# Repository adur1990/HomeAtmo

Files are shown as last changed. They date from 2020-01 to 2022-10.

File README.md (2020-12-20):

# HomeAtmo
Simple ESP32 based BME680 indoor air quality sensor.

## Overview
This is a very basic project, which reads the sensor values from a BME680 sensor (temperature, humidity VOC, CO2 air quality) and computes the [Indoor Air Quality (IAQ)](https://en.wikipedia.org/wiki/Indoor_air_quality) and implemented as an HomeKit Accessory.

## DIY
**Disclaimer: this project uses the proprietary [Bosch Sensortec Environmental Cluster (BSEC) Arduino Library](https://github.com/BoschSensortec/BSEC-Arduino-library) with their own [license](https://github.com/BoschSensortec/BSEC-Arduino-library/blob/master/LICENSE). If you do not agree with this license, you can not use this software. Everything not from the BSEC library uses the GPL 3.0 license**
### Software
#### HomeKit
All relevant HomeKit information has to be given in the `creds.h` file.
Use `include/creds.h.example` as a reference.

#### Wi-Fi
To be able to connect to your Wi-Fi network, provide your SSID and PSK in the `creds.h` file (see above).

#### Flashing
This project uses [PlatformIO](https://platformio.org), which makes it pretty easy to deploy the code.
Simply connect the ESP32 to you computer, import this repo into PlatformIO and use PlatformIO's upload command.
Thats it for the software part.
Head on to the hardware section.

### Hardware
For this project, I use an [ESP32 WROOM NodeMCU Development Board](https://www.amazon.de/dp/B071P98VTG) (~10€) and the [Bosch BME680 Sensor Breakout from BlueDot](https://www.amazon.de/gp/product/B075Y21H24) (~25€).
There are for sure cheaper solutions from AliExpress or similar, but I was not patient enough, so I went with Amazon. If you use different hardware, you have to adjust the case dimensions.

For the power supply, I use a rather standard USB 5V DC adapter to power the ESP32 via the 5V and GND pins.

#### Wiring
The wiring is quite easy.
Connect the VIN pin to the 3V pin of the ESP32, GND to GND.
For I2C, connect the SCK pin to the ESP's SCL (GPIO22) and SDI to SDA (GPIO21).
The ground cable of your USB power supply goes to the 5V pin on the ESP32 and GND to a free GND.

The following fritzing sketch will show you an example, but your actual pinout can be different, so be careful here!

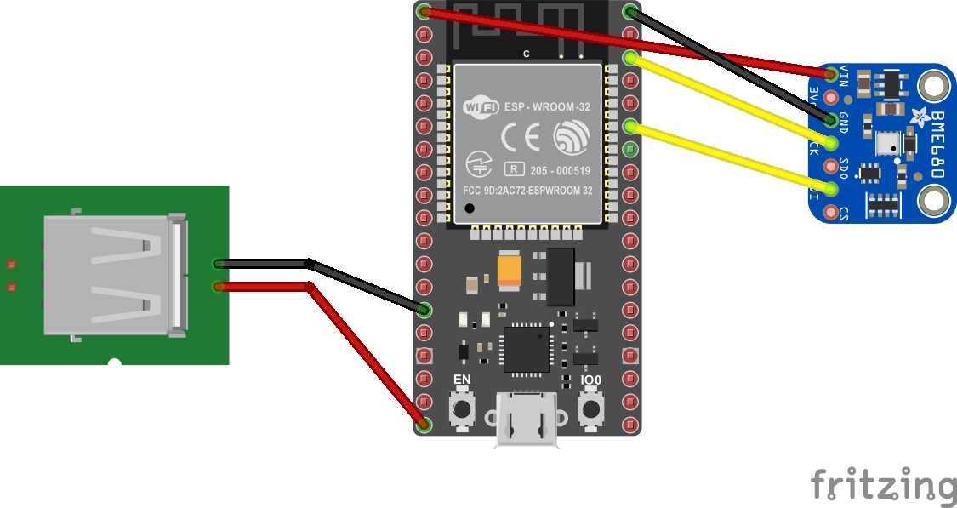
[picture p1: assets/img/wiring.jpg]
LWiring


#### Packaging
*Note: The case does not have a micro USB connector. Flash the ESP32 BEFORE assembling the sensor!*

Use the provided [STL](assets/HomeAtmo.stl) to print the case. Adjust the dimensions according to your hardware.
Pack everything into the case as seen on the following image:

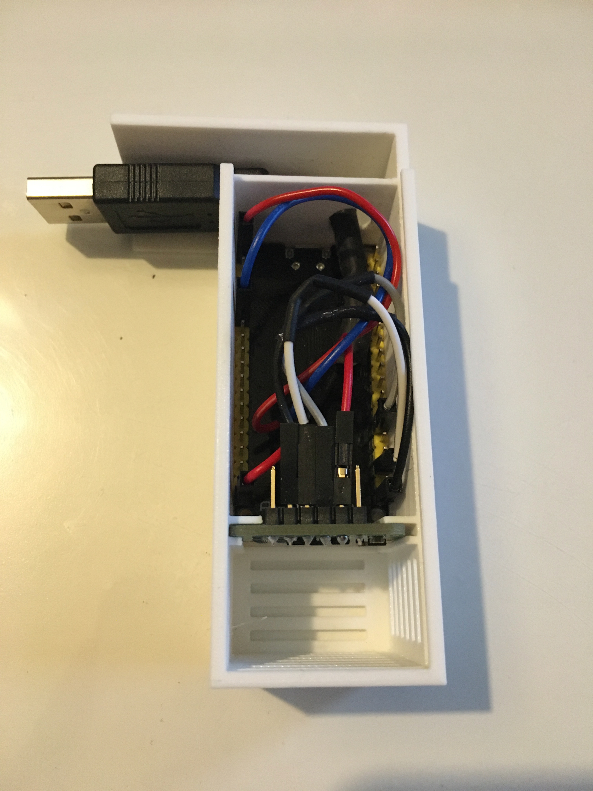
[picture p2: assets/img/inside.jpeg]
Look Inside


You have to fiddle the wires for power supply through the small hole and connect the jumper wires to the corresponding 5V and GND pins.
The sensor itself is put vertically into the corresponding compartment.
Finally, the lid must be closed by pushing it into the slots provided.

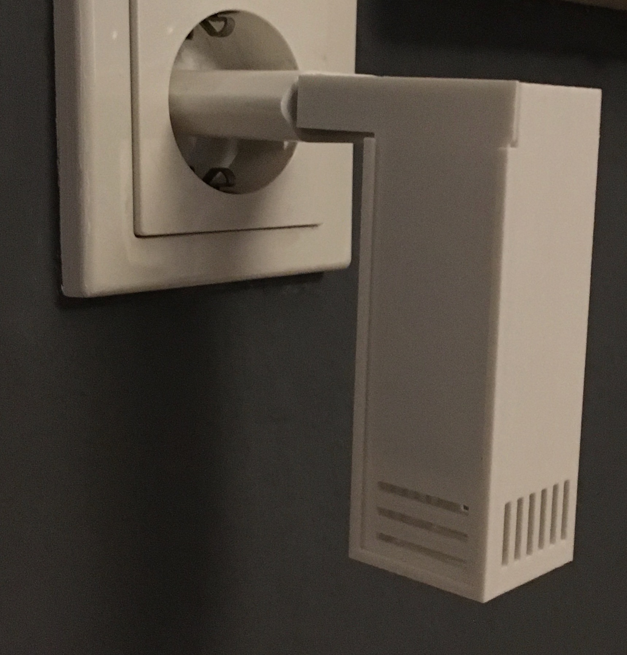
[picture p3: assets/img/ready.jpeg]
Ready


I glued the USB connector to the case for more stability.
Connect the USB cable to the power supply, plug everything to the wall socket and you are done!

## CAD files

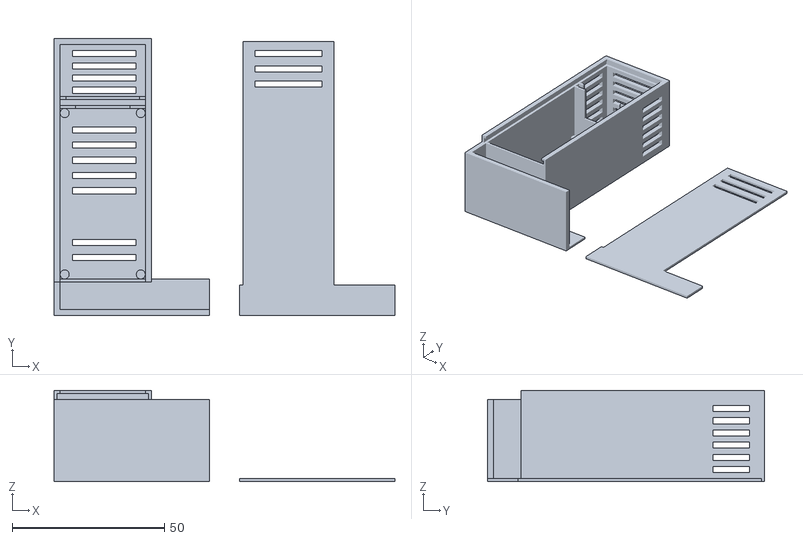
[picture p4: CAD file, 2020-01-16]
assets/HomeAtmo.stl
112.0 x 91.0 x 30.0

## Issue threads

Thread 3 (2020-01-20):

Add option to get only the values without graphs

adur1990, 2020-01-20:
For some cases, only the values without the graphs are intereseting (e.g. using iOS shortcuts to show the current temperatur in the widges view)

adur1990, 2020-02-02:
Already possible with individual endpoints.

Closed 2020-02-02.

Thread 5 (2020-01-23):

Reduce sample rate

adur1990, 2020-01-23:
Currently, the sensor is pulled as fast as possible. But this is unnecessary and consumes a lot of power. This should be reduced to something like every 5 minutes.

Closed 2020-02-02.

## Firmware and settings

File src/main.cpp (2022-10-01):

/******* INCLUDES *******/
#include <Arduino.h>
#include <Wire.h>
#include <WiFi.h>
#include <ESPmDNS.h>
#include <EEPROM.h>

#include <AsyncTCP.h>
#include "ESPAsyncWebServer.h"

#include <homekit/types.h>
#include <homekit/homekit.h>
#include <homekit/characteristics.h>
#include <arduino_homekit_server.h>

#include "bsec.h"

#include "creds.h"


/******* SERVER *******/
AsyncWebServer server(80);
String log_content = "";
uint8_t log_count = 0;

/******* HOMEKIT VARIABLES *******/
extern "C" homekit_server_config_t homekit_config;
extern "C" homekit_characteristic_t temperature_chara;
extern "C" homekit_characteristic_t humidity_chara;
extern "C" homekit_characteristic_t iaq_chara;
extern "C" homekit_characteristic_t co2_chara;
extern "C" homekit_characteristic_t voc_chara;


/******* SENSOR *******/
#define STATE_SAVE_PERIOD UINT32_C(360 * 60 * 1000)
Bsec sensor;
const uint8_t bsec_config_iaq[] = {
    #include "config.txt"
};
uint8_t bsec_state[BSEC_MAX_STATE_BLOB_SIZE] = {0};
uint16_t state_update_counter = 0;
void check_IAQ_sensor_status(void);
void load_state(void);
void update_state(void);
void err_leds(void);


void log(String log_msg) {
    Serial.print(log_msg);

    if (log_count == 200) {
        log_content = "";
        log_count = 0;
    }

    log_content = log_content + log_msg;
    log_count++;
}


void check_IAQ_sensor_status(void) {
    if (sensor.status != BSEC_OK) {
        if (sensor.status < BSEC_OK) {
            log("#### BSEC error: " + String(sensor.status) + "\n");
            for (;;)
                err_leds();
        } else {
            log("#### BSEC warning: " + String(sensor.status) + "\n");
        }
    }

    if (sensor.bme680Status != BME680_OK) {
        if (sensor.bme680Status < BME680_OK) {
            log("#### BME680 error: " + String(sensor.bme680Status) + "\n");
            for (;;)
                err_leds();
        } else {
            log("#### BME680 warning: " + String(sensor.bme680Status) + "\n");
        }
    }
}


void load_state(void) {
    if (EEPROM.read(0) == BSEC_MAX_STATE_BLOB_SIZE) {
        // Existing state in EEPROM
        log("Reading state from EEPROM");

        for (uint8_t i = 0; i < BSEC_MAX_STATE_BLOB_SIZE; i++) {
            bsec_state[i] = EEPROM.read(i + 1);
        }

        sensor.setState(bsec_state);
        check_IAQ_sensor_status();
    } else {
        // Erase the EEPROM with zeroes
        log("Erasing EEPROM");

        for (uint8_t i = 0; i < BSEC_MAX_STATE_BLOB_SIZE + 1; i++) {
            EEPROM.write(i, 0);
        }

        EEPROM.commit();
    }
}


void update_state(void) {
    bool update = false;
    if (state_update_counter == 0) {
        /* First state update when IAQ accuracy is >= 3 */
        if (sensor.iaqAccuracy >= 3) {
            update = true;
            state_update_counter++;
        }
    } else {
        /* Update every STATE_SAVE_PERIOD minutes */
        if ((state_update_counter * STATE_SAVE_PERIOD) < millis()) {
            update = true;
            state_update_counter++;
        }
    }

    if (update) {
        sensor.getState(bsec_state);
        check_IAQ_sensor_status();

        log("Writing state to EEPROM");

        for (uint8_t i = 0; i < BSEC_MAX_STATE_BLOB_SIZE ; i++) {
            EEPROM.write(i + 1, bsec_state[i]);
        }

        EEPROM.write(0, BSEC_MAX_STATE_BLOB_SIZE);
        EEPROM.commit();
    }
}


void err_leds(void) {
    log("Error...\n");
    digitalWrite(LED_BUILTIN, HIGH);
    delay(100);
    digitalWrite(LED_BUILTIN, LOW);
    delay(100);
}

void setup() {
    Serial.begin(115200);


    pinMode(LED_BUILTIN, OUTPUT);


    Serial.print("#### Connecting to WiFi");
    WiFi.begin(SSID, PSK);

    while (WiFi.status() != WL_CONNECTED) {
        delay(500);
        Serial.print(".");
    }
    Serial.println("");

    tcpip_adapter_set_hostname(TCPIP_ADAPTER_IF_STA ,"HomeAtmo");


    server.on("/", HTTP_GET, [] (AsyncWebServerRequest *request) {
        String message = "No message sent";
        request->send(200, "text/plain", log_content);
    });

    server.begin();

    log("#### WiFi connected.\n");
    log("#### IP address: ");
    log(WiFi.localIP().toString());
    log("\n#### Hostname: ");
    log(WiFi.getHostname());
    log("\n#### Wi-Fi Connected.\n");


    log("#### Setting up sensor.\n");


    EEPROM.begin(BSEC_MAX_STATE_BLOB_SIZE + 1);


    Wire.begin();
    sensor.begin(BME680_I2C_ADDR_SECONDARY, Wire);
    check_IAQ_sensor_status();

    sensor.setConfig(bsec_config_iaq);
    check_IAQ_sensor_status();

    load_state();

    bsec_virtual_sensor_t sensor_list[5] = {
        BSEC_OUTPUT_STATIC_IAQ,
        BSEC_OUTPUT_CO2_EQUIVALENT,
        BSEC_OUTPUT_SENSOR_HEAT_COMPENSATED_TEMPERATURE,
        BSEC_OUTPUT_SENSOR_HEAT_COMPENSATED_HUMIDITY,
        BSEC_OUTPUT_BREATH_VOC_EQUIVALENT
    };

    sensor.updateSubscription(sensor_list, 5, BSEC_SAMPLE_RATE_ULP);
    check_IAQ_sensor_status();

    log("#### Setting up HomeKit.\n");
    arduino_homekit_setup(&homekit_config);

    log("#### Everything set up\n");
}


void loop() {
    if (sensor.run()) {
        float tmp_temp = sensor.temperature;
        float tmp_humi = sensor.humidity;
        float tmp_co2 = sensor.co2Equivalent;
        float tmp_voc = sensor.breathVocEquivalent;
        float tmp_acc = sensor.iaqAccuracy;
        float tmp_iaq = sensor.iaq;

        temperature_chara.value.float_value = tmp_temp;
        homekit_characteristic_notify(&temperature_chara, temperature_chara.value);

        humidity_chara.value.float_value = tmp_humi;
        homekit_characteristic_notify(&humidity_chara, humidity_chara.value);

        co2_chara.value.float_value = tmp_co2;
        homekit_characteristic_notify(&co2_chara, co2_chara.value);

        voc_chara.value.float_value = tmp_voc;
        homekit_characteristic_notify(&voc_chara, voc_chara.value);

        iaq_chara.value.float_value = tmp_iaq;
        homekit_characteristic_notify(&iaq_chara, iaq_chara.value);


        log("\nTemperature: ");
        log(String(tmp_temp));

        log("\nHumidity: ");
        log(String(tmp_humi));

        log("\nCO2: ");
        log(String(tmp_co2));

        log("\nVOC: ");
        log(String(tmp_voc));

        log("\nIAQ RAW: ");
        log(String(tmp_iaq));

        log("\nIAQ: ");
        log(String(tmp_iaq));

        log("\nIAQ Acuuracy: ");
        log(String(tmp_acc));

        update_state();
    } else {
        check_IAQ_sensor_status();
    }
}

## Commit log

2020-01-08 Add sensor; update webpage to show sensor data
2020-01-09 Fix bug causing the ESP to crash because timing issues
    [main.cpp]
2020-01-09 Fix wrong pressure y-axis scale
2020-01-14 Add STL file for the case
    [HomeAtmo.stl]
2020-01-16 Update the case
    [HomeAtmo.stl]
2020-02-02 Slow down sensor reading to every 5 minutes; remove (non working) dayly notification (closes #5, closes #7)
2020-02-09 Use different task for IAQ
    In the previous commit, all sensors were queried every 5 minutes.
    Unfortunately, the IAQ sensor loses its calibration after that time.
    So, all values are queries every 5 minutes, except the IAQ sensor,
    which is queried every 10 seconds.
2020-02-09 Cleanup setup log printing
2020-02-10 Revert changes introduced in recent commits
    In the recent past, I added a moving average for the IAQ
    and a task specific for the IAQ. Both caused different
    issues (e.g., if you do not sample the IAQ sensor often enough,
    it will lose its calibration, rendering it useless).
    This commit reverts these changes.
    [main.cpp]
2020-12-21 Fix bug where log output could overflow.
    [main.cpp]
2022-10-01 Reduce sampling rate to reduce power consumption
    [config.txt]
